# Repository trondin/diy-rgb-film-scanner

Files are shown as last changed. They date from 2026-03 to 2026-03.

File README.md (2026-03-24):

# DIY RGB Film Scanner — Canon PowerShot S5 IS + Smartphone OLED

**High-quality 35mm slide/negative digitization on a budget**

Uses a cheap used Canon PowerShot S5 IS (€20–30), CHDK, sequential RGB (or WRGB) backlight from any OLED phone, and fully open-source Python tools.

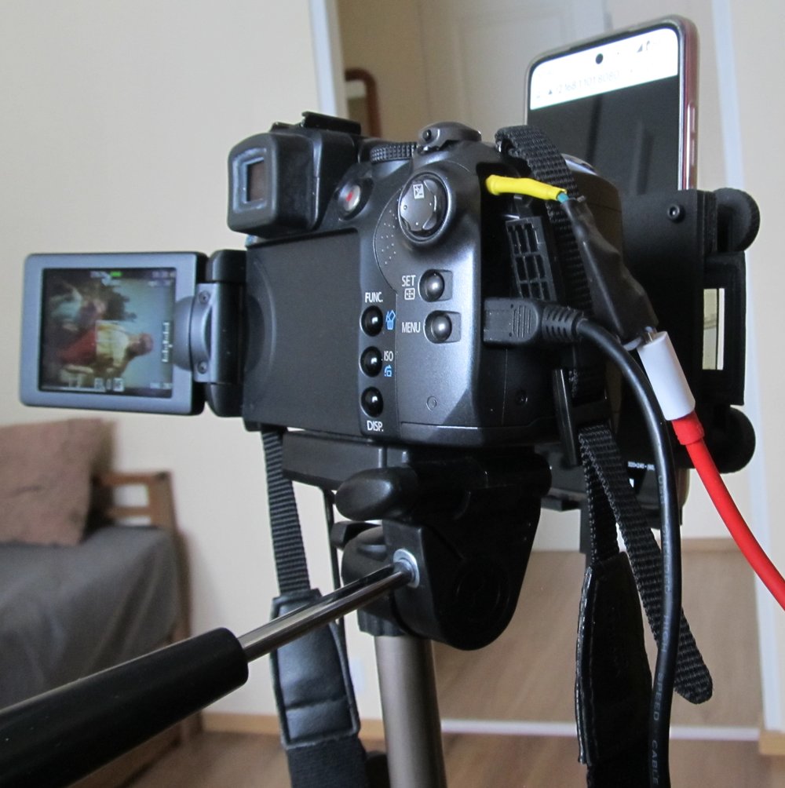
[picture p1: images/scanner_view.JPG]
Real build


## Why this project?

- Professional-level results without spending €1000+ on a dedicated film scanner  
- Bypasses Bayer filter limitations by shooting separate full-resolution RAW frames for each color channel  
- Excellent dynamic range and color accuracy thanks to RAW control and dark-frame subtraction  
- Everything is 3D-printable and costs almost nothing beyond the old camera

## Key Advantages of the S5 IS for this task

- Super Macro mode allows focusing extremely close → very simple mechanical design with no stray light  
- Large enough sensor (1/2.5") and 8 MP resolution ideal for film (larger files from 20+ MP bring mostly noise)  
- CHDK enables reliable RAW shooting — essential for proper RGB channel combination

## Features

### Hardware
- Complete parametric OpenSCAD model (film holder for 35mm, lens adapter, phone mount, tension bolt/nut system)  
- Uses the camera in Super Macro mode — no complex optics required

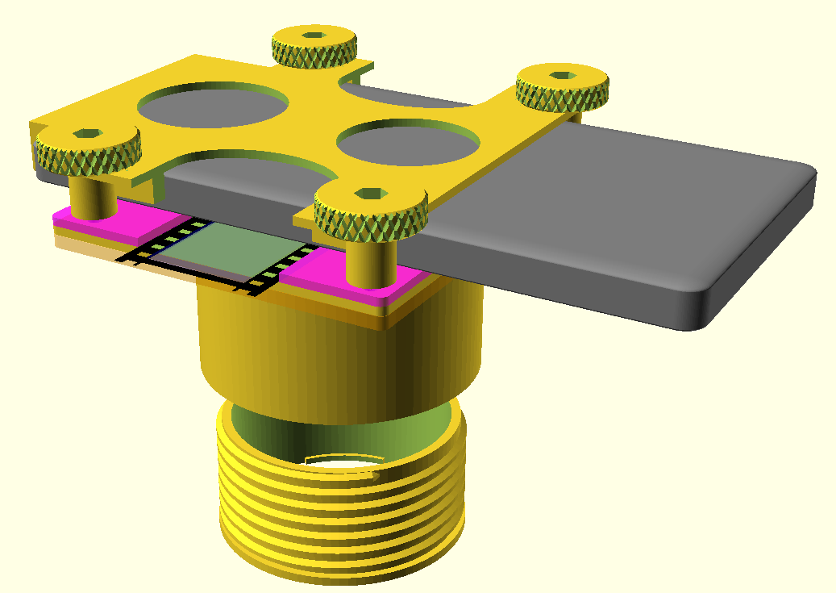
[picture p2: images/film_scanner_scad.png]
Full scanner assembly


### Scanning Software (`python/Film_scanner/film_scanner.py`)
- Live view from the camera via gPhoto2  
- One-click scan sequences: **White only**, **RGB**, **WRGB**, **Custom**, **Custom RGB**  
- Built-in web server — control the RGB backlight rectangle and brightness directly from your phone browser  
- Automatic saving of RAW + JPEG with smart naming and optional dark frames  
- Dark frame support for noise subtraction

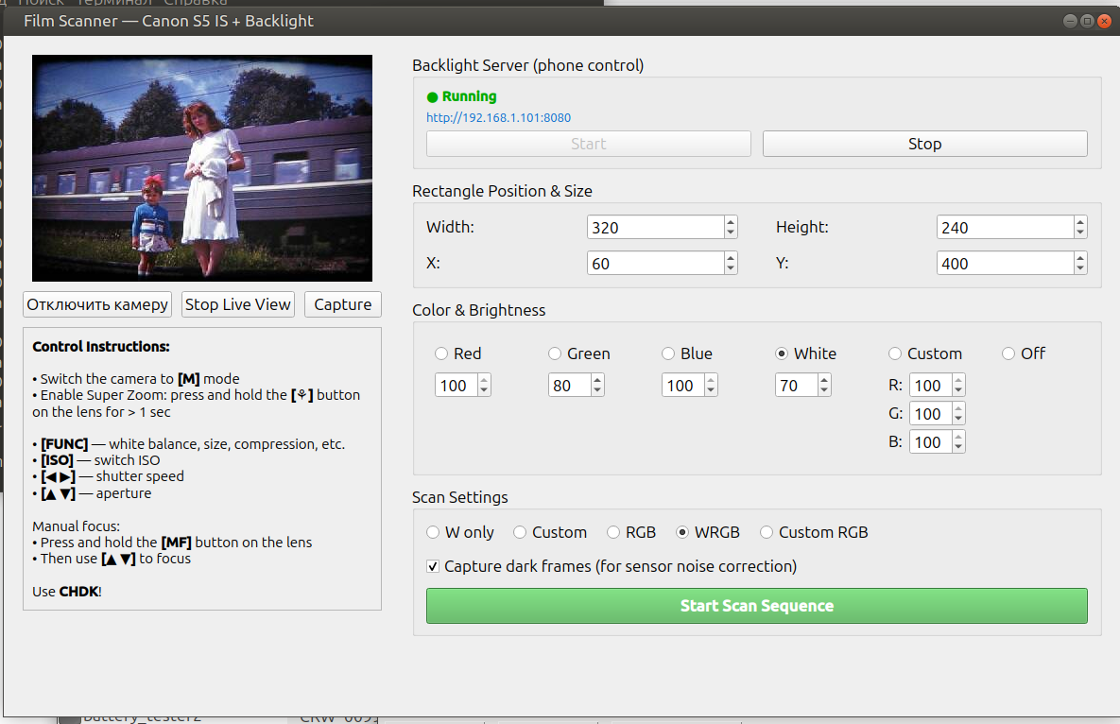
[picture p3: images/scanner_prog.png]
Scanning interface


### RGB2W Processor (`python/rgb2w/rgb2w_gui.py`)
- Automatic dark-frame subtraction  
- Optional bad-pixel correction (5×5 median filter)  
- Spectral sensitivity compensation  
- 99.95% percentile normalization + soft highlight roll-off (preserves highlight structure)  
- Outputs: `_rgb.tiff` (16-bit), `_w.tiff` (16-bit), `_rgb.jpg`

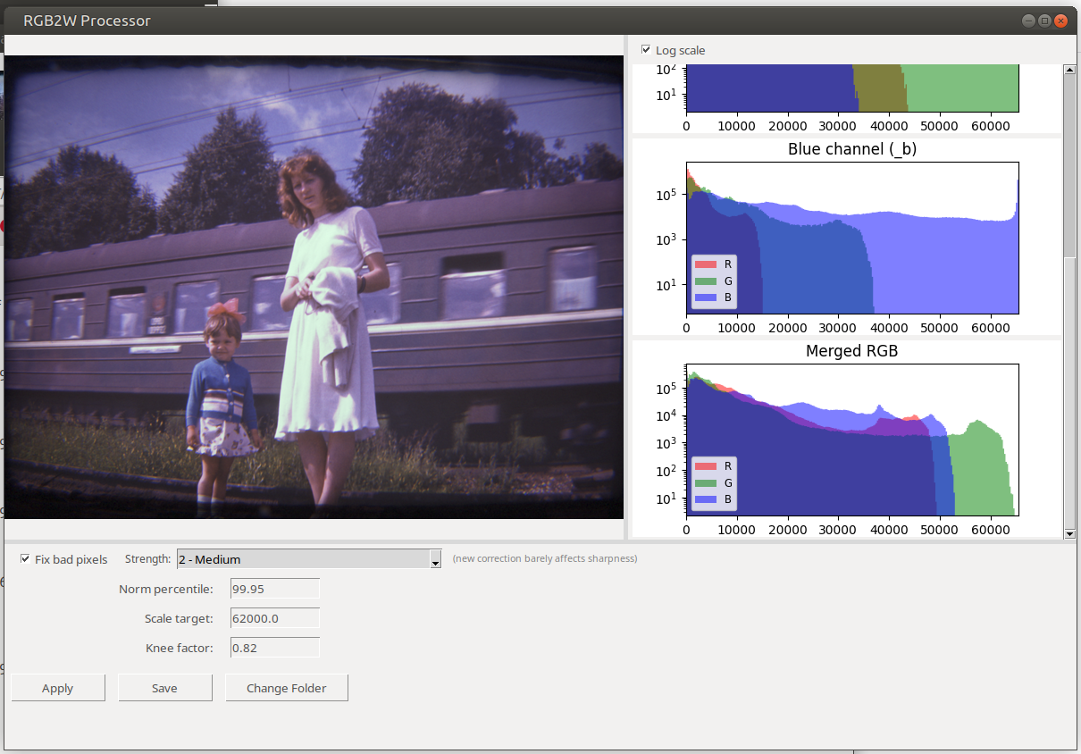
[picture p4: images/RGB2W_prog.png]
RGB2W Processor


### TIFF Crop Tool (`python/tiff_crop/tiff_crop.py`)
- Lossless 16-bit crop and 90° rotation (preserves full bit depth)  
- Interactive crop rectangle with fixed aspect ratios (1:1, 3:4, 4:3)  
- Saves with zlib compression

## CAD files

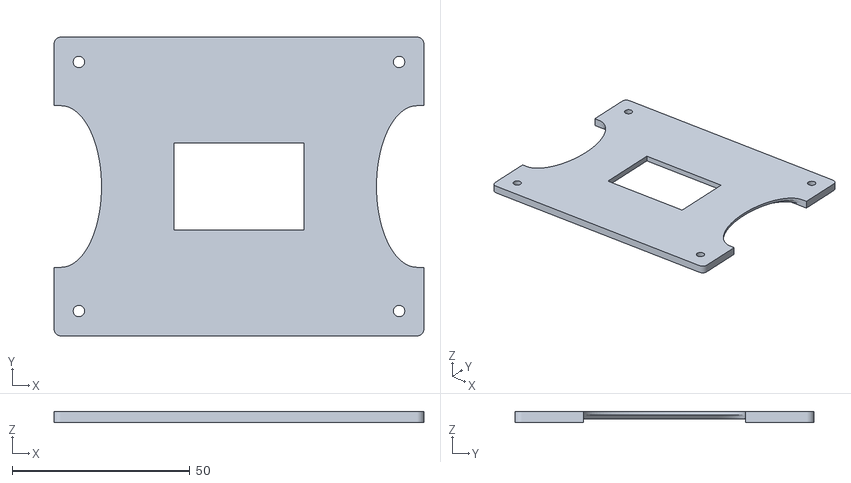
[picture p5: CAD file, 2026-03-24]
openscad/Canon_film_scanner/up_hold.stl
104.0 x 84.0 x 3.00

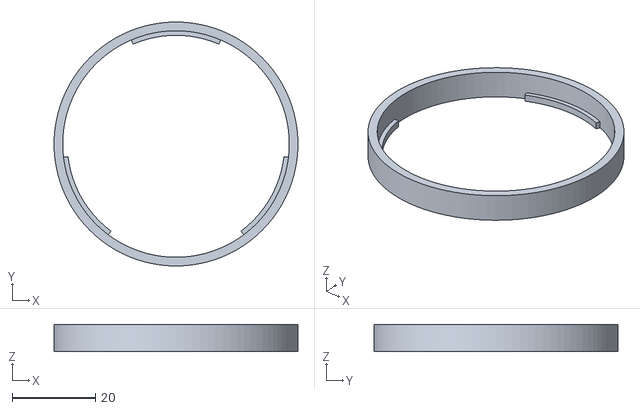
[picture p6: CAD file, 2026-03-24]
openscad/Canon_film_scanner/ring.stl
58.6 x 58.6 x 6.50

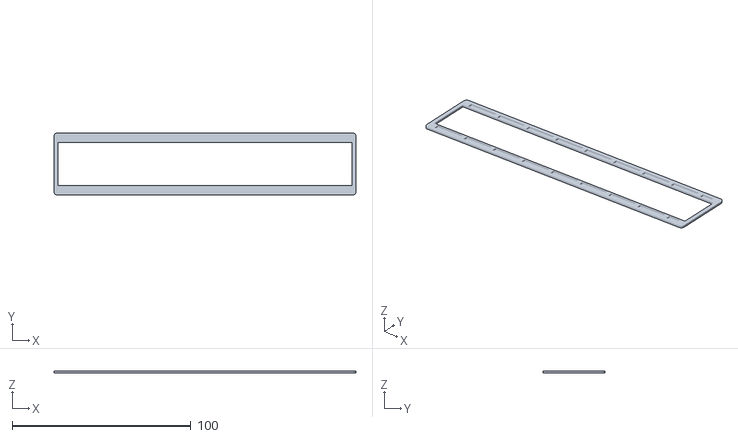
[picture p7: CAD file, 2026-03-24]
openscad/Canon_film_scanner/frame_cup.stl
169.0 x 34.9 x 1.20

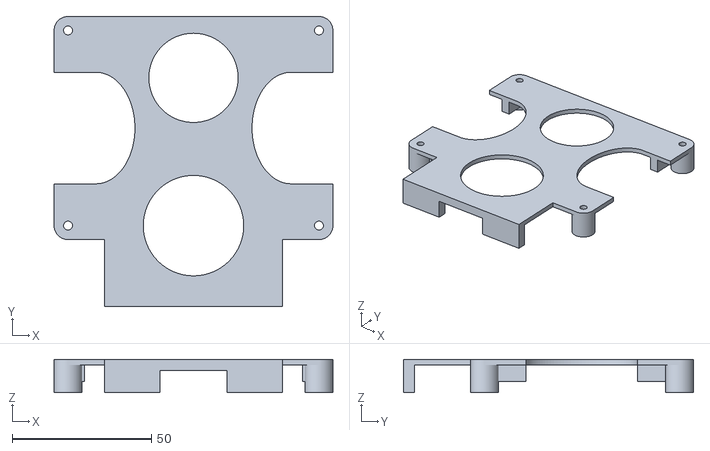
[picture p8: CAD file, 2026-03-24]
openscad/Canon_film_scanner/phone_holder.stl
100.0 x 104.0 x 12.0

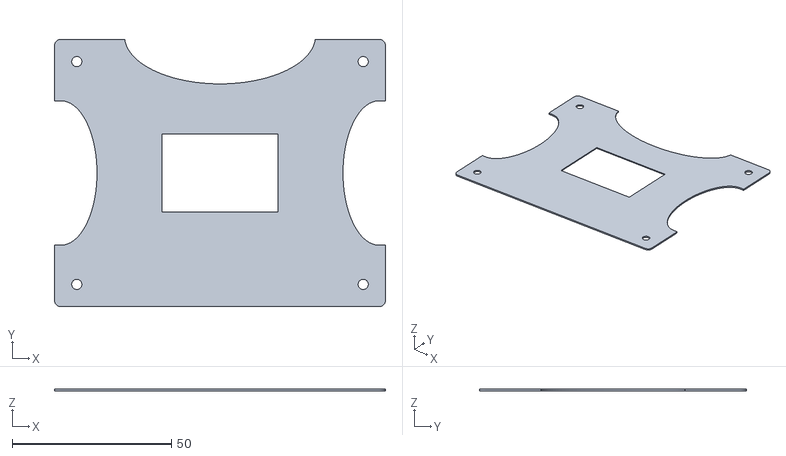
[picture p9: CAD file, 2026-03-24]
openscad/Canon_film_scanner/bl_hold.stl
104.0 x 84.0 x 0.6

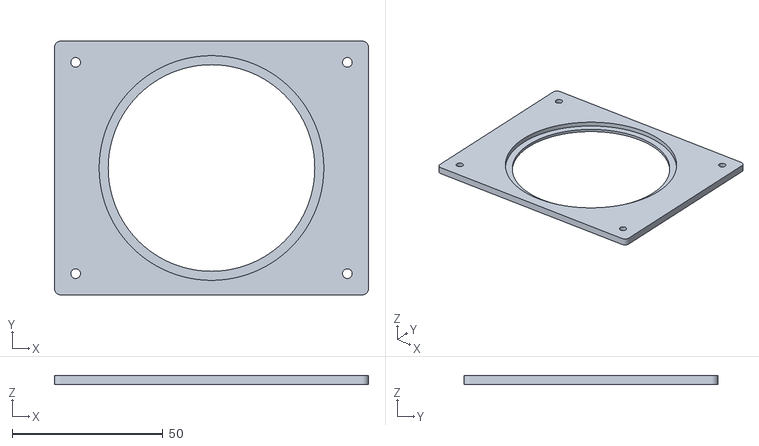
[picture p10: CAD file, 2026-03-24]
openscad/Canon_film_scanner/lens_hold.stl
104.0 x 84.0 x 3.00

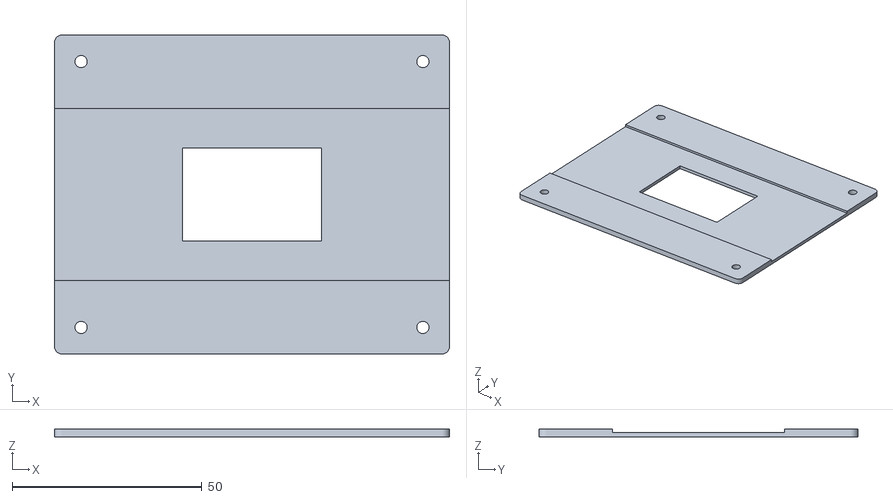
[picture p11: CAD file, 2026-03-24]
openscad/Canon_film_scanner/bottom_hold.stl
104.0 x 84.0 x 2.00

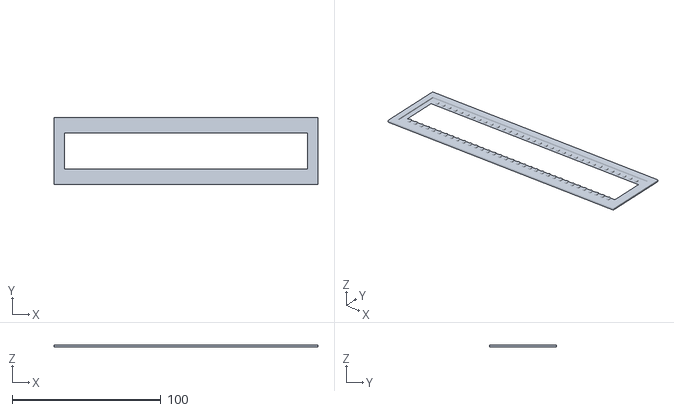
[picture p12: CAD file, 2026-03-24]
openscad/Canon_film_scanner/film_frame.stl
177.5 x 45.0 x 1.20

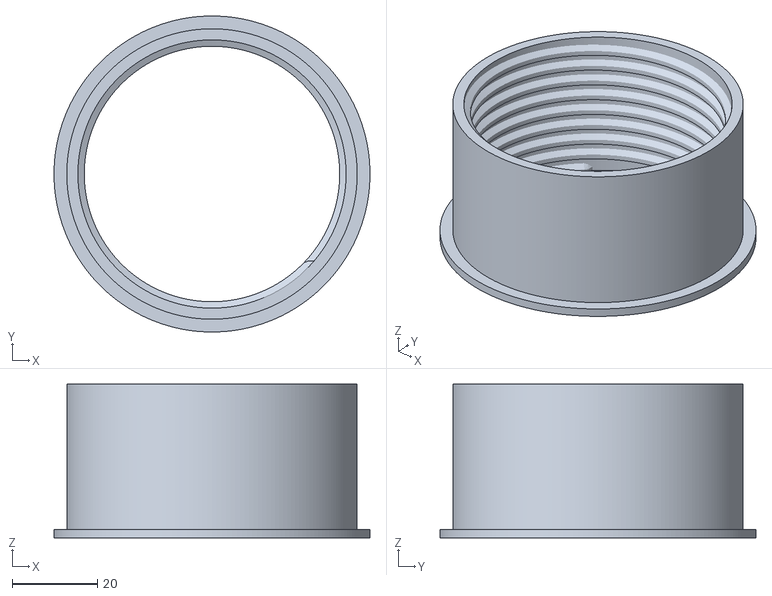
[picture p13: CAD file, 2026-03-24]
openscad/Canon_film_scanner/nut.stl
74.0 x 74.0 x 36.0

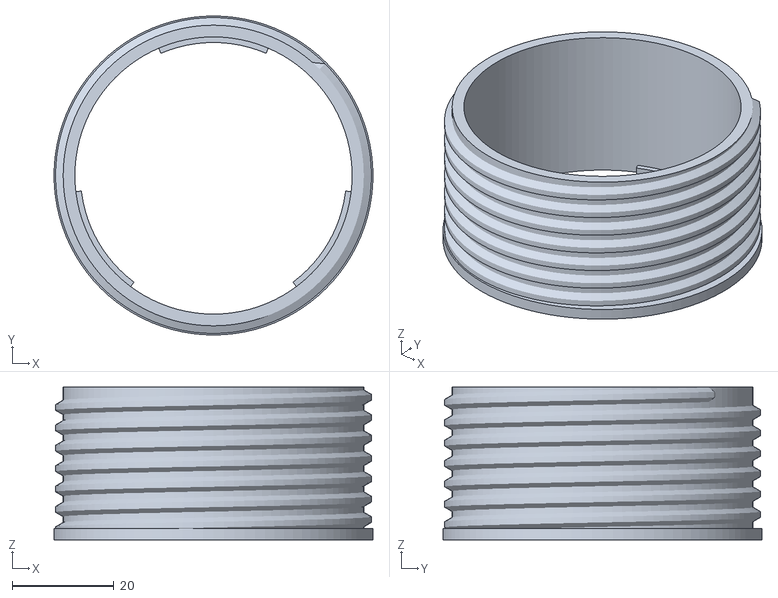
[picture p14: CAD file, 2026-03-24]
openscad/Canon_film_scanner/bolt.stl
62.6 x 62.6 x 30.0

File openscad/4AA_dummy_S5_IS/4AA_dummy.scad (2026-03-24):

$fn=96;

// AA();
//AAx4();

AAx4_shell_down();
translate([0,0, 35])  mirror([0,0,1]) AAx4_shell_up();



module AA()
{
  cylinder(h=50.5, d=5.2, center=true);
  translate([0,0,-0.5]) cylinder(h=49.5, d=14.4, center=true);
}

module AAx4()
{
  AA();
  translate([14.4,0,0]) 
  { 
    rotate([180,0,0]) AA();  
    rotate([0,0,-20]) translate([14.4,0,0]) AA();
  }
  rotate([0,0,-70]) translate([14.4,0,0]) rotate([180,0,0]) AA(); 
}

DIA=11;
STEP=14.5;
a1=-75;
a2=-13;  
WALL=5.2;
w=2;
  
module AAx4_shell_down()
{

  H=5;


  id = DIA - 2*w;
  iw = WALL - w;
  cz = H/2;
  difference()
  {
    union()
    {
      difference()
      {
        union()
        {
          cylinder(h=H, d=DIA, center=true);
          translate([STEP,0]) cylinder(h=H, d=DIA, center=true);
          translate([STEP,0]) rotate(a2) translate([STEP,0]) cylinder(h=H, d=DIA, center=true);
          rotate(a1) translate([STEP,0]) cylinder(h=H, d=DIA, center=true);

          H1=H+3;
          DIA1=DIA-w-0.2;
          translate([0,0, 1.5])
          {  
            cylinder(h=H1, d=DIA1, center=true);
            translate([STEP,0]) cylinder(h=H1, d=DIA1, center=true);
            translate([STEP,0]) rotate(a2) translate([STEP,0]) cylinder(h=H1, d=DIA1, center=true);
            rotate(a1) translate([STEP,0]) cylinder(h=H1, d=DIA1, center=true);      
          }
      
          hull() 
          {
            translate([0,0.8]) cylinder(h=H,d=WALL,center=true); 
            translate([STEP,0.8]) cylinder(h=H,d=WALL,center=true);
          }
          hull() 
          {
            translate([STEP,0]) 
            {
              cylinder(h=H,d=WALL,center=true);
              rotate(a2) translate([STEP,0]) cylinder(h=H,d=WALL,center=true);
            }
          }
          hull()
          {
            translate([0,-0.5]) cylinder(h=H,d=WALL,center=true); 
            rotate(a1) translate([STEP,-0.5]) cylinder(h=H,d=WALL,center=true); 
          }
        }

        translate([0,0,6]) 
        {
          cylinder(h=11, d=id, center=true);
          translate([STEP,0]) cylinder(h=11, d=id, center=true);
          translate([STEP,0]) rotate(a2) translate([STEP,0]) cylinder(h=11, d=id, center=true);
          rotate(a1) translate([STEP,0]) cylinder(h=11, d=id, center=true);
   

          hull()
          {
            translate([0,0.8])cylinder(h=11,d=iw,center=true);
            translate([STEP,0.8]) cylinder(h=11,d=iw,center=true); 
          }
          hull()
          {
            translate([STEP,0])
            {
              cylinder(h=11,d=iw,center=true);
              rotate(a2) translate([STEP,0]) cylinder(h=11,d=iw,center=true); 
            }
          }
          hull()
          {
            translate([0,-0.5]) cylinder(h=11,d=iw,center=true);
            rotate(a1) translate([STEP,-0.5]) cylinder(h=11,d=iw,center=true); 
          }
        }
      }
  
      DIA2=7;
      translate([STEP,0,1]) rotate(a2) translate([STEP,0]) cylinder(h=H-3, d=DIA2, center=true);
      rotate(a1) translate([STEP,0,1]) cylinder(h=H-3, d=DIA2, center=true);
    }
    translate([STEP,0,1]) rotate(a2) translate([STEP,0])
    {
      translate([2,0,0]) cylinder(h=20, d=1.8, center=true);
      translate([-2,0,0]) cylinder(h=20, d=1.8, center=true);
    }
    rotate(a1) translate([STEP,0,1])
    {
      translate([2,0,0]) cylinder(h=20, d=1.8, center=true);
      translate([-2,0,0]) cylinder(h=20, d=1.8, center=true);
    }    
    
  }
}

  
module AAx4_shell_up()
{
  H=43;

  id = DIA - w;
  iw = WALL - w;
  cz = H/2;

  difference()
  {
    union()
    {
      cylinder(h=H, d=DIA, center=true);
      translate([STEP,0]) cylinder(h=H, d=DIA, center=true);
      translate([STEP,0]) rotate(a2) translate([STEP,0]) cylinder(h=H, d=DIA, center=true);
      rotate(a1) translate([STEP,0]) cylinder(h=H, d=DIA, center=true);

      hull() 
      {
        translate([0,0.8]) cylinder(h=H,d=WALL,center=true); 
        translate([STEP,0.8]) cylinder(h=H,d=WALL,center=true);
      }
      hull() 
      {
        translate([STEP,0]) {
          cylinder(h=H,d=WALL,center=true);
          rotate(a2) translate([STEP,0]) cylinder(h=H,d=WALL,center=true);
        }
      }
      hull()
      {
        translate([0,-0.5]) cylinder(h=H,d=WALL,center=true); 
        rotate(a1) translate([STEP,-0.5]) cylinder(h=H,d=WALL,center=true); 
      }
    }

    translate([0,0,3]) 
    {
      cylinder(h=H+1, d=id, center=true);
      translate([STEP,0]) cylinder(h=H+1, d=id, center=true);
      translate([STEP,0]) rotate(a2) translate([STEP,0]) cylinder(h=H+1, d=id, center=true);
      rotate(a1) translate([STEP,0]) cylinder(h=H+1, d=id, center=true);

      hull()
      {
        translate([0,0.8]) cylinder(h=H+1,d=iw,center=true);
        translate([STEP,0.8]) cylinder(h=H+1,d=iw,center=true); 
      }
      hull()
      {
        translate([STEP,0])
        {
          cylinder(h=H+1,d=iw,center=true);
          rotate(a2) translate([STEP,0]) cylinder(h=H+1,d=iw,center=true); 
        }
      }
      hull()
      {
        translate([0,-0.5]) cylinder(h=H+1,d=iw,center=true);
        rotate(a1) translate([STEP,-0.5]) cylinder(h=H+1,d=iw,center=true); 
      }
    }
    translate([8,0, -cz]) rotate([90,0,0]) cylinder(h=10, d=3, center=true);  
    translate([8,0.8, -cz]) cylinder(h=10, d=3, center=true); 
    translate([0,-8, -cz]) rotate([-a1+90, 90,0]) cylinder(h=10, d=3, center=true);
    translate([1.8,-7.5, -cz]) cylinder(h=10, d=3, center=true);  
  }
}  
  
  
  

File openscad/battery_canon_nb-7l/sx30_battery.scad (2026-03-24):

$fn=96;
//translate([-16.1, -22.6, -8.9]) color("Blue", alpha=1) import("dummy.stl");

//color("red", alpha=0.5)
box();
translate([0, 0, 7.25]) cup();

module cup()
{
  difference()
  {
    cube([30-0.4,42-0.4,3], center=true);
    
    translate([-6.8, -16.0, 0])
    {
      cylinder(h=20, d=3.3, center=true);       
      translate([0, 0, 1.5]) cylinder(h=4, d=6.8, center=true);
    }

    translate([11, 17.5, 0])
    {
      cylinder(h=20, d=3.3, center=true);       
      translate([0, 0, 1.5]) cylinder(h=4, d=6.8, center=true);
    }
  }

}

module box()
{
  difference()
  { 
    union()
    {
      difference()
      {
        cube([31.7,45,17.5], center=true);
        translate([0, 0, 8]) cube([30,42,5], center=true);
        translate([0, 1, 2.1]) cube([26,38,16], center=true);
      }
      translate([-6, -18, -1]) cube([14,4,13], center=true);
      translate([-6.8, -16.0, -5]) cylinder(h=6, d=10, center=true);
      translate([-6.8, -16.0, -1.5]) cylinder(h=14, d=6, center=true);    
      translate([11, 17.5, -5]) cylinder(h=6, d=10, center=true);
      translate([11, 17.5, -1.5]) cylinder(h=14, d=6, center=true);      
      translate([13, 19.5, -1.5]) cube([1,1,14], center=true);    
    }
    step=5.05-1.8;
    translate([-1.8, -22, -5.2]) cube([2,4,4], center=true);
    translate([-1.8-step, -22, -5.2]) cube([2,4,4], center=true);
    translate([-1.8-2*step, -22, -5.2]) cube([2,4,4], center=true);
    translate([-1.8-3*step, -22, -5.2]) cube([2,4,4], center=true);

    translate([-1.8, -20.0, 1.5]) cylinder(h=20, d=1.8, center=true);
    translate([-1.8, -17.0, 1.5]) cylinder(h=20, d=1.8, center=true);
    translate([-1.8, -18, 5]) cube([2, 5, 3], center=true);
    translate([-1.8, -15.9, 3]) cube([2, 2, 6], center=true);
  
    translate([-1.8-3*step, -20.0, 1.5]) cylinder(h=20, d=1.8, center=true);
    translate([-1.8-3*step, -17.0, 1.5]) cylinder(h=20, d=1.8, center=true);
    translate([-1.8-3*step, -18, 5]) cube([2, 5, 3], center=true);
    translate([-1.8-3*step, -15.9, 3]) cube([2, 2, 6], center=true);

    translate([-15.2, -22.3, -4.9]) cube([2,4,4], center=true);
    translate([14.7, -22.3, -4.9]) cube([2.5,4,4], center=true);
   
    translate([-6.8, -16.0, 0])
    {
      cylinder(h=20, d=3.3, center=true);    
      hull()
      {
        translate([0, 0, -7]) cylinder(h=6, d=6.8, center=true, $fn=6); 
        translate([0, 0, -6]) cylinder(h=6, d=3.3, center=true, $fn=6);  
      }
    }
  
    translate([11, 17.5, 0])
    {
      cylinder(h=20, d=3.3, center=true);    
      hull()
      {
        translate([0, 0, -7]) cylinder(h=6, d=6.8, center=true, $fn=6); 
        translate([0, 0, -6]) cylinder(h=6, d=3.3, center=true, $fn=6);  
      }
    }  
    translate([-13, 18.5, 4]) cube([14,3,12], center=true);
  }
}

      

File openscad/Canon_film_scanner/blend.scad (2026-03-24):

$fn=96;
include <BOSL2/std.scad>
include <BOSL2/screws.scad>


assembly();
//lens_hold();  
//bottom_hold();
//ring();
//nut();
//up_hold(); 
// projection() bl();
//translate([0,0, 0]) bl_hold();
//color("silver", 0.8) translate([0,8,0]) bl();
//knob();  
//phone_holder(); 
//stencil();
 
//film();
//film_frame(4); 
//  translate([0,0, 2]) film_frame_cup(4); 
 
module assembly()
{
  translate([0,0, 30]) bolt();
  translate([0,0, 66]) rotate([180,0,0]) nut();
  
  translate([0,0, 85]) color("red", 0.8) bottom_hold();
  translate([0,0, 87.5]) color("fuchsia", 0.8) up_hold();  
  translate([0,0, 82.4]) color("orange", 0.5) lens_hold();  

  translate([0,0, 89.5]) mirror([0,0,1]) bl_hold();
  translate([0,0, 90.2]) bl_hold();
  
  translate([0,0, 85.5])
  {
    film();
    translate([0,0, 0.3]) film_frame(4); 
    translate([0,0, 0.9]) mirror([0,0,1]) film_frame_cup(4);   
  }
  
  translate([0,20,96]) rotate([0,0,90]) color("gray") phone();
  translate([0,0,102]) phone_holder();  
  
//  for (x = [-1, 1], y = [-1, 1])
//    translate([x * 90/2, y * 70/2, 100]) knob();  
 }
 
 
 module phone()
 {
   hull() for (x = [-1, 1], y = [-1, 1])
   {
     translate([x * 150/2, y * 67/2,  5-1.25]) scale([1,1,0.25]) sphere(d=10);    
     translate([x * 150/2, y * 67/2, -5+1.25]) scale([1,1,0.25]) sphere(d=10);    
   } 
 }

module stencil()
{
  H=1;
  X=50;
  Y=45;
  difference() 
  {
    cube([X+20, Y+20, H], center = true);        
    {
      for (x = [-1, 1], y = [-1, 1])
        translate([x * (X/2-1), y * (Y/2-1), 0])
          cylinder(h = 10, d = 4, center = true);
    } 
    
    cube([X, Y, 10], center = true);        
    

  }     
}

 
 
 module phone_holder()
{
  difference()
  {
    union()
    {
      hull() for (x = [-1, 1], y = [-1, 1])
        translate([x * 90/2, y * 70/2, 0])
          cylinder(h = 2, d = 10, center = true);   
      for (x = [-1, 1], y = [-1, 1])
        translate([x * 90/2, y * 70/2, -6])
          cylinder(h = 10, d = 10, center = true);   
        translate([41, 0, -4]) cube([4, 70, 6], center=true);           
        translate([-41, 0, -4]) cube([4, 70, 6], center=true);        
        
        translate([22, -62, -6]) cube([20, 4, 10], center=true);        
        translate([-22, -62, -6]) cube([20, 4, 10], center=true);           
        translate([0, -44, 0]) cube([64, 40, 2], center=true);          
        translate([0, -62, -2]) cube([64, 4, 2], center=true);        
        
    }
      translate([35, 0, 0]) hull()
      { 
        scale([0.7,1,1]) cylinder(h = 20, d=40, center = true);   
        translate([15, 0, 0]) cube([4, 40, 20], center=true);     
      }  
        
      translate([-35, 0, 0]) hull()
      { 
        scale([0.7,1,1]) cylinder(h = 20, d=40, center = true);   
        translate([-15, 0, 0]) cube([4, 40, 20], center=true);     
      } 
      
      translate([0, -35, 0]) cylinder(h = 20, d=36, center = true); 
      translate([0, 18, 0]) cylinder(h = 20, d=32, center = true); 
      
      for (x = [-1, 1], y = [-1, 1])
        translate([x * 90/2, y * 70/2, 0])
          cylinder(h = 30, d = 3.2, center = true);    
  }
} 

 module knob()
{  
  height=6;
  diameter=22;    
  chamfer=0.6;
    
  difference()      
  {
    union()
    { 
      translate([0,0,chamfer]) cylinder(d=diameter,h=height-2*chamfer);           
      translate([0,0,height-chamfer]) cylinder(d1=diameter,d2=diameter-chamfer*2, h=chamfer);      
      cylinder(d1=diameter-chamfer*2,d2=diameter, h=chamfer);          
    }      
           
    translate([0,0,-1]) cylinder(d=3.2,h=height+2);     
    translate([0,0,height-3]) cylinder(d=6.8,h=4, $fn=6);      
    
    //knurls
    for(i=[0:29], t=[120,-120]) rotate([0,0,i*12])
      linear_extrude(height=height+0.1, twist=height/45*t)
        translate([diameter/2,0]) circle(r=0.5, $fn=4);    
  }
}

 
module ring()
{
  difference()
  {
    cylinder(h=6.5, d=58.6, center=true);
    cylinder(h=10, d=54.4, center=true);  
  }

  intersection()
  {
    difference()
    {
      translate([0,0,-2.45]) cylinder(h=1.6, d=58.6, center=true);
      cylinder(h=10, d=52.2, center=true);  
    }

    for(i = [0:2]) 
    {      
      rotate([0, 0, i*120]) translate([0, 0, 0]) 
      {
        hull()
        {
          cylinder(h = 10, d = 0.1, center = true);
          translate([0, 56/2,0]) cube([24,0.2,10], center = true);
        }
      }
    } 
  }
  
  difference()
  {
    translate([0,0,-2.15]) cylinder(h=2.2, d=58.6+4, center=true);
    cylinder(h=10, d=54.4, center=true);  
  }  
}


module bolt()
{
  translate([0,0,11.75]) difference()
  {
    trapezoidal_threaded_rod(d = 62, pitch = 4, length = 30,thread_angle = 60, thread_depth=1.5);           
    cylinder(h=100, d=54.4, center=true);  
  } 
  ring();
}

module bottom_hold()
{
  difference() 
  {
    hull()
    {
      for (x = [-1, 1], y = [-1, 1])
        translate([x * 100/2, y * 80/2, 0])
          cylinder(h = 2, d = 4, center = true);
    }  
    cube([36.5, 24.5, 10], center = true);  
    translate([0,0, 0.6]) cube([120, 35+10+0.4, 0.85], center = true);     
    for (x = [-1, 1], y = [-1, 1])
      translate([x * 90/2, y * 70/2, 0])
          cylinder(h = 10, d = 3.2, center = true);      
  }
}

module bl()
{
  difference()
  {
    cube([59, 75, 0.21], center = true); 
  
    translate([15,-36, 0]) hull()
    {
      cylinder(h = 5, d = 6, center = true);  
      translate([0,-5, 0])  cylinder(h = 5, d = 6, center = true);  
    }
    translate([-15,-36, 0]) hull()
    {
      cylinder(h = 5, d = 6, center = true);  
      translate([0,-5, 0])  cylinder(h = 5, d = 6, center = true);  
    } 
  }
}

module bl_hold()
{
  H=0.6;
  difference() 
  {
    hull()
    {
      for (x = [-1, 1], y = [-1, 1])
        translate([x * 100/2, y * 80/2, 0])
          cylinder(h = H, d = 4, center = true);
    } 
    
     
    cube([36.5, 24.5, 20], center = true);      
 
    // holes for bolts
    for (x = [-1, 1], y = [-1, 1])
      translate([x * 90/2, y * 70/2, 0])
          cylinder(h = 10, d = 3.2, center = true);      
    translate([-50,0, 0]) hull()
    {  
      scale([0.5,1,1]) cylinder(h = 10, d = 45.4, center = true);
      translate([-30,0, 0]) cube([2, 45.4, 10], center = true);    
    }          
 
    translate([50,0, 0]) hull()
    {  
      scale([0.5,1,1]) cylinder(h = 10, d = 45.4, center = true);
      translate([30,0, 0]) cube([2, 45.4, 10], center = true);    
    }          


 
    
    translate([0,10, -0.2]) cube([60, 80, 0.21], center = true);      
    translate([0,43, 0])  scale([1, 0.5,1]) cylinder(h = 10, d = 60, center = true);
  }     

    translate([15,-28, 0]) hull()
    {
      cylinder(h = H, d = 5, center = true);  
      translate([0,-5, 0])  cylinder(h = H, d = 5, center = true);  
    }
    translate([-15,-28, 0]) hull()
    {
      cylinder(h = H, d = 5, center = true);  
      translate([0,-5, 0])  cylinder(h = H, d = 5, center = true);  
    }    
}


module up_hold()
{
  H=3;
  difference() 
  {
    hull()
    {
      for (x = [-1, 1], y = [-1, 1])
        translate([x * 100/2, y * 80/2, 0])
          cylinder(h = H, d = 4, center = true);
    } 
    
     
    cube([36.5, 24.5, 20], center = true);      
    translate([0,0, -H/2+0.44]) cube([120, 45.4, 0.9], center = true);  // film tray  
    // holes for bolts
    for (x = [-1, 1], y = [-1, 1])
      translate([x * 90/2, y * 70/2, 0])
          cylinder(h = 10, d = 3.2, center = true);      
    translate([-50,0, 0]) 
    {
      hull()
      {  
        scale([0.5,1,1]) cylinder(h = 10, d = 45.4, center = true);
        translate([-30,0, 0]) cube([2, 45.4, 10], center = true);    
      }          
      translate([0,0, -H/2]) hull()
      {
        scale([0.7,1,1]) cylinder(h = 0.2, d = 45.4, center = true);
        translate([0,0, 2]) scale([0.5,1,1]) cylinder(h = 0.1, d = 45.4, center = true);
      }
    }
  
    translate([50,0, 0])
    { 
      hull()
      {  
        scale([0.5,1,1]) cylinder(h = 10, d = 45.4, center = true);
        translate([30,0, 0]) cube([2, 45.4, 10], center = true);    
      }          

      translate([0,0, -H/2]) hull()
      {
        scale([0.7,1,1]) cylinder(h = 0.2, d = 45.4, center = true);
        translate([0,0, 2]) scale([0.5,1,1]) cylinder(h = 0.1, d = 45.4, center = true);
      }        
    }

  
    
  }     
}


module lens_hold()
{
    difference() 
    {
      hull()
      {
        for (x = [-1, 1], y = [-1, 1])
          translate([x * 100/2, y * 80/2, 0])
            cylinder(h = 3, d = 4, center = true);
      }  
      translate([0,0, 0.6]) cylinder(d=74.4, h=2, center=true); 
      translate([0,0, 0.6]) cylinder(d=68.4, h=10, center=true);       
      for (x = [-1, 1], y = [-1, 1])
        translate([x * 90/2, y * 70/2, 0])
            cylinder(h = 10, d = 3.2, center = true);      
  }
}
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

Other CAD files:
openscad/Canon_film_scanner/BOSL2/constants.scad
openscad/Canon_film_scanner/BOSL2/affine.scad
openscad/Canon_film_scanner/BOSL2/attachments.scad
openscad/Canon_film_scanner/BOSL2/beziers.scad
openscad/Canon_film_scanner/BOSL2/bosl1compat.scad
openscad/Canon_film_scanner/BOSL2/bottlecaps.scad
openscad/Canon_film_scanner/BOSL2/builtins.scad
openscad/Canon_film_scanner/BOSL2/color.scad
openscad/Canon_film_scanner/BOSL2/comparisons.scad
openscad/Canon_film_scanner/BOSL2/coords.scad
openscad/Canon_film_scanner/BOSL2/cubetruss.scad
openscad/Canon_film_scanner/BOSL2/distributors.scad
openscad/Canon_film_scanner/BOSL2/drawing.scad
openscad/Canon_film_scanner/BOSL2/fnliterals.scad
openscad/Canon_film_scanner/BOSL2/geometry.scad
openscad/Canon_film_scanner/BOSL2/isosurface.scad
openscad/Canon_film_scanner/BOSL2/linalg.scad
openscad/Canon_film_scanner/BOSL2/linear_bearings.scad
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

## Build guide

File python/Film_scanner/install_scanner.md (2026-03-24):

**Film Scanner — Canon PowerShot S5 IS + RGB Backlight Controller**

Desktop application (PyQt6) for digitizing film negatives using a Canon PowerShot S5 IS camera controlled via gPhoto2 and a DIY RGB backlight panel controlled from a phone.

**Features:**

- Live view from the camera
- Manual and automatic multi-color scanning (W / RGB / WRGB / Custom)
- Web server for real-time backlight control from any device on the local network
- Automatic saving of RAW + JPEG with proper naming
- Dark frame support for noise subtraction
- Configurable backlight rectangle position and size

**Installation:**

Bash

```
# 1. Install system dependencies
sudo apt install python3-pip libgphoto2-dev

# 2. Install Python packages
pip install PyQt6 gphoto2

# 3. Run
python3 film_scanner.py
```

Connect your Canon S5 IS via USB, start the backlight server, open the address shown in the app on your phone, and start scanning.

Ready for batch digitization of 35mm format film.
